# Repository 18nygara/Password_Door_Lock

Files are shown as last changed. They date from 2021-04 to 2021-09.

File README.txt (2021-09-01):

Password based door locking mechanism - 12 key allows user to input a password which will be reflected on the screen provided on the unit. USB interface allows 
one to set a password and change settings in the device, software is not included in the repo.

WARNING! ~~~ IF TRYING TO COPY THIS REPO, IT WILL NOT WORK ON YOUR LOCAL MACHINE ~~~

Because of the absolute pathing on KiCAD file libraries, downloading this project will NOT allow one to modify the design.
All footprint, 3D, and library modules were provided via UltraLibrarian, SnapEDA, DigiKey, or were custom designed - they can be resourced but not copied directly from here.

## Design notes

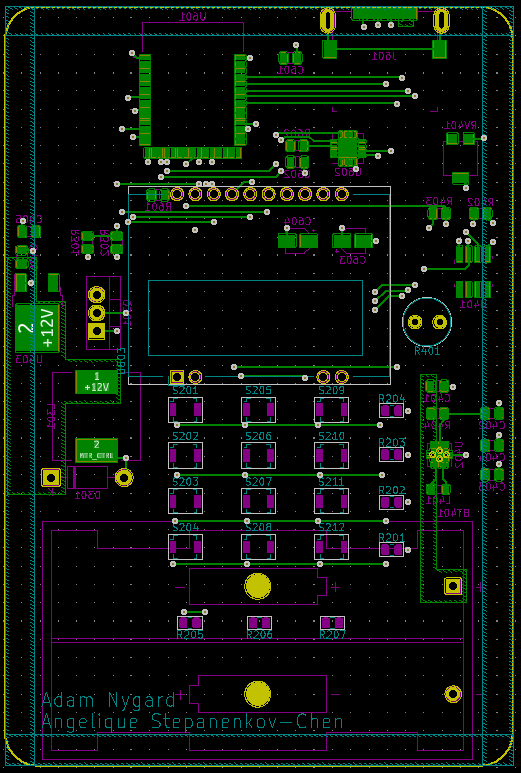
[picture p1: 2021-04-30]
PCB_3D_img/Final_Project_Bottom.PNG

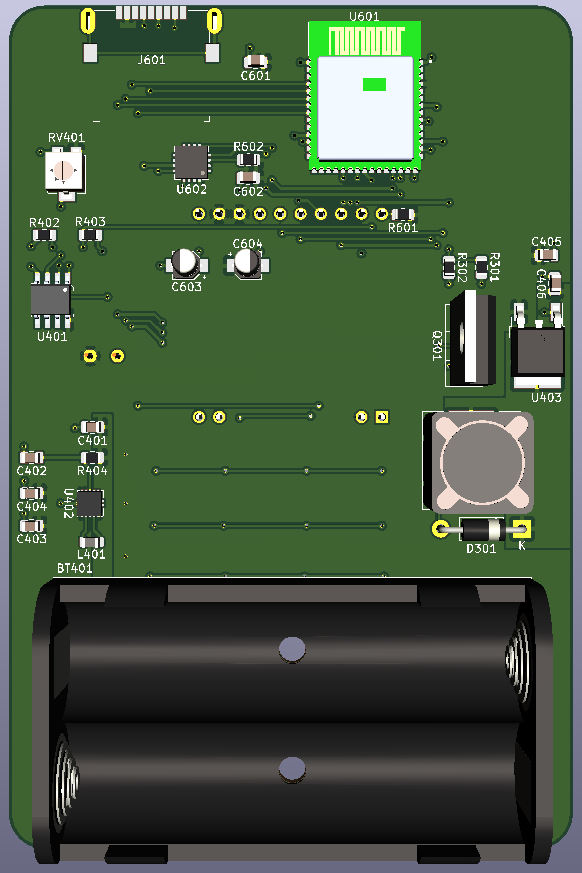
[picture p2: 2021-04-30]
PCB_3D_img/FinalProject_Bottom_3D.PNG

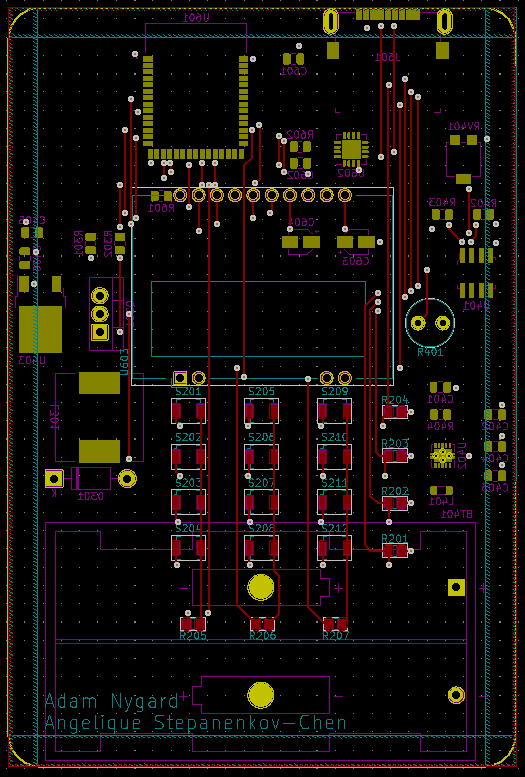
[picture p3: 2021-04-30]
PCB_3D_img/FinalProject_Top.PNG

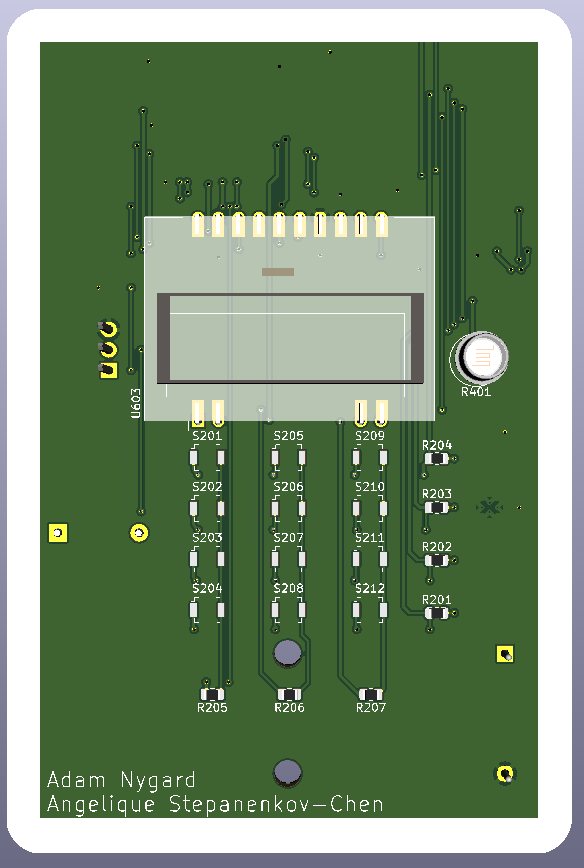
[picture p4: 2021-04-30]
PCB_3D_img/FinalProject_Top_3D.PNG

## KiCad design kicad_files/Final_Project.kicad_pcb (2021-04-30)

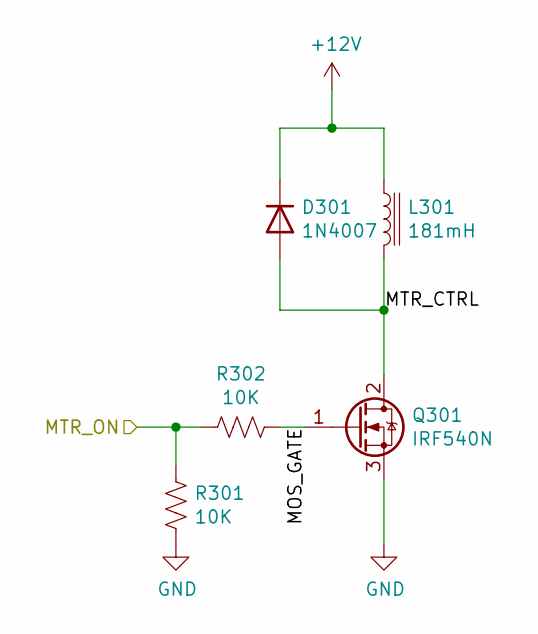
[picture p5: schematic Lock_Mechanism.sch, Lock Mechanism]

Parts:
D301: 1N4007; D_DO-41_SOD81_P10.16mm_Horizontal
L301: 181mH; L_Taiyo-Yuden_NR-10050_9.8x10.0mm
Q301: IRF540N; TO-220-3_Vertical
R301, R302: 10K; R_0805_2012Metric

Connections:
+12V: D301.1 (K), L301.1; also elsewhere on the board
/Lock_Mechanism/MOS_GATE: Q301.1 (G), R302.2
/Lock_Mechanism/MTR_CTRL: D301.2 (A), L301.2, Q301.2 (D)
/Lock_Mechanism/MTR_ON: R301.1, R302.1; also elsewhere on the board
GND: Q301.3 (S), R301.2; also elsewhere on the board

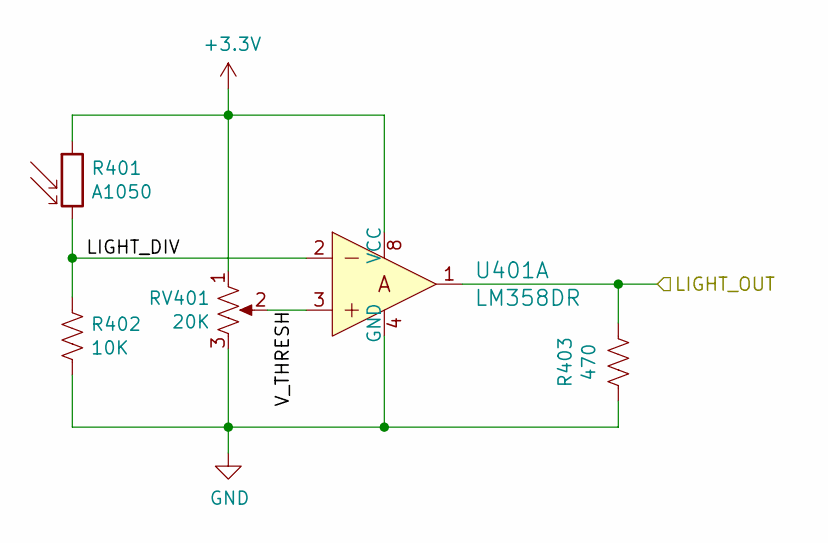
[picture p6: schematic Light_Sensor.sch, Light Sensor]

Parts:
R401: A1050; R_LDR_D6.4mm_P3.4mm_Vertical
R402: 10K; R_0805_2012Metric
R403: 470; R_0805_2012Metric
RV401: 20K; Potentiometer_Bourns_3214W_Vertical
U401: LM358DR; SOIC-8_W3.9mm; MPN LM358DR; Digi-Key_PN 296-1014-1-ND

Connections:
+3V3: R401.1, RV401.1, U401.8 (VCC); also elsewhere on the board
/Light_Sensor/LIGHT_DIV: R401.2, R402.1, U401.2
/Light_Sensor/LIGHT_OUT: R403.1, U401.1; also elsewhere on the board
/Light_Sensor/V_THRESH: RV401.2, U401.3
GND: R402.2, R403.2, RV401.3, U401.4 (GND); also elsewhere on the board

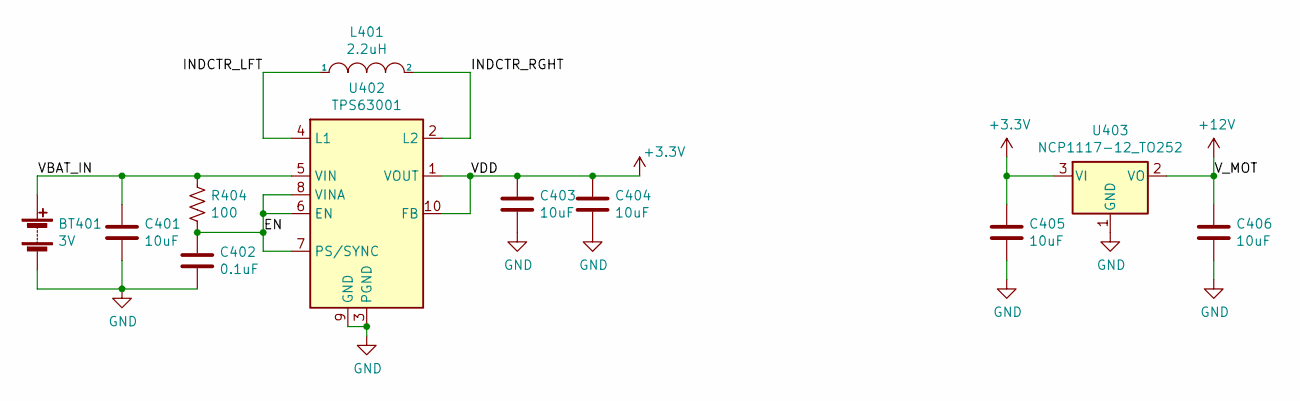
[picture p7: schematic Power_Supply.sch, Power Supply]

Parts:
BT401: 3V; BatteryHolder_Keystone_2462_2xAA
C401, C403, C404, C405, C406: 10uF; C_0805_2012Metric
C402: 0.1uF; C_0805_2012Metric
L401: 2.2uH; L_0805_2012Metric
R404: 100; R_0805_2012Metric
U402: TPS63001; Texas_DRC0010J_ThermalVias
U403: NCP1117-12_TO252; TO-252-2

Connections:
+3V3: C403.1, C404.1, C405.1, U402.1 (VOUT), U402.10 (FB), U403.3 (VI); also elsewhere on the board
+12V: C406.1, U403.2 (VO); also elsewhere on the board
/Power_Supply/EN: C402.1, R404.2, U402.6 (EN), U402.7 (PS/SYNC), U402.8 (VINA)
/Power_Supply/INDCTR_LFT: L401.1, U402.4 (L1)
/Power_Supply/INDCTR_RGHT: L401.2, U402.2 (L2)
/Power_Supply/VBAT_IN: BT401.1 (+), C401.1, R404.1, U402.5 (VIN)
GND: BT401.2 (-), C401.2, C402.2, C403.2, C404.2, C405.2, C406.2, U402.3 (PGND), U402.9 (GND), U402.11 (PGND), U403.1 (GND); also elsewhere on the board

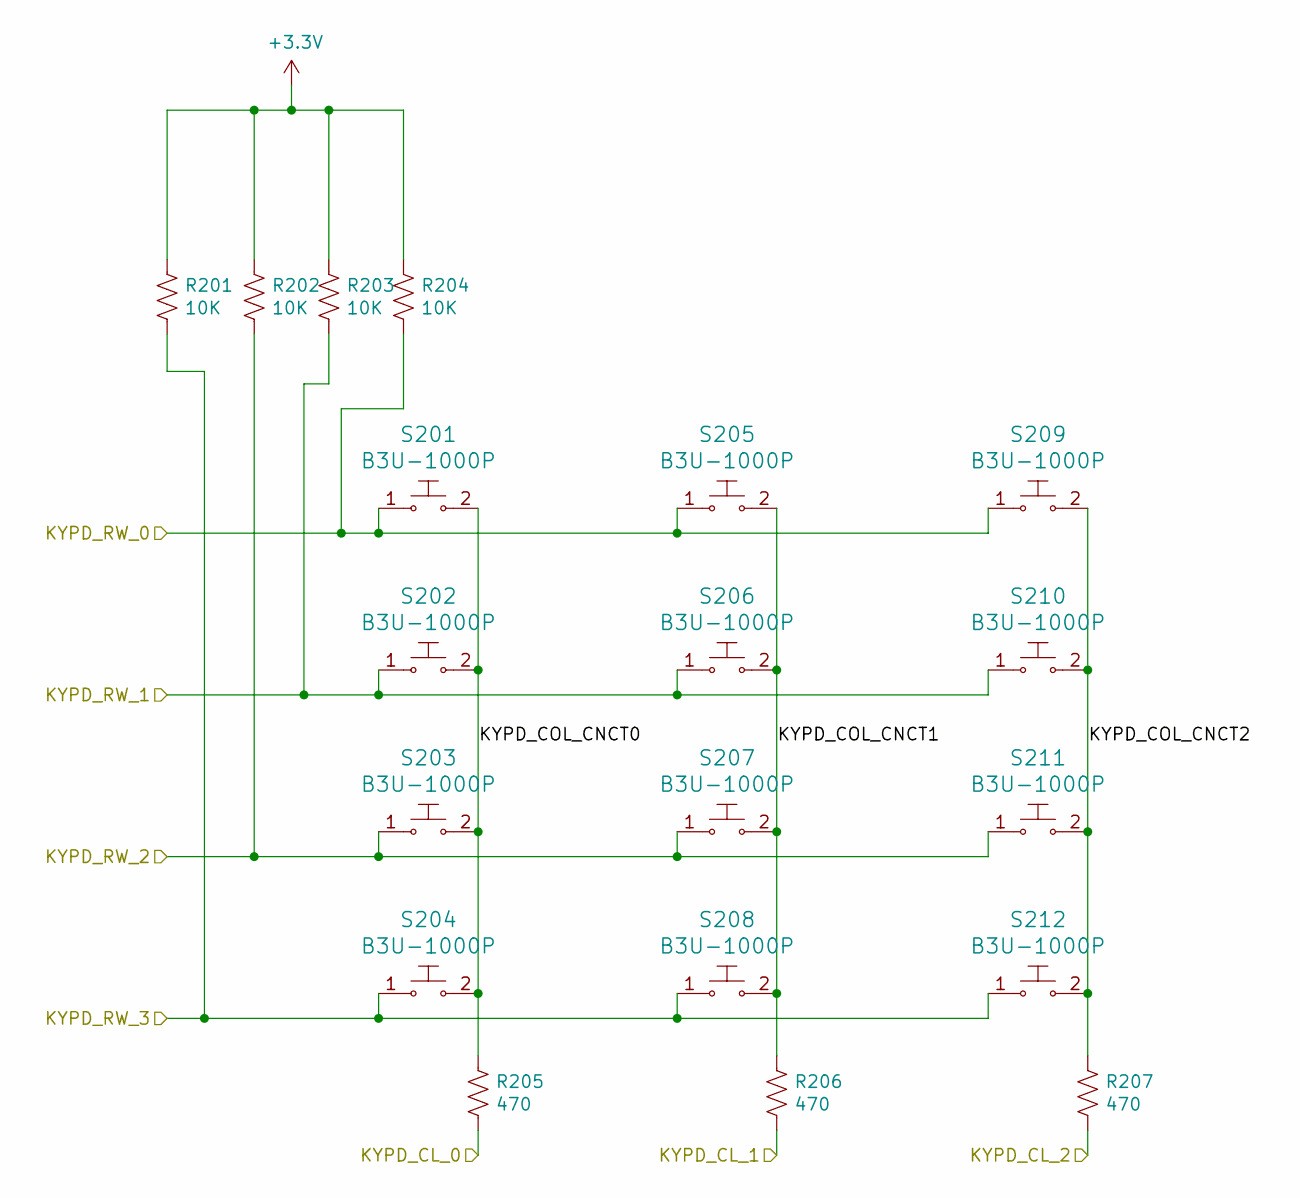
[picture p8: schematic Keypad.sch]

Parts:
R201, R202, R203, R204: 10K; R_0805_2012Metric
R205, R206, R207: 470; R_0805_2012Metric
S201, S202, S203, S204, S205, S206, S207, S208, S209, S210, S211, S212: B3U-1000P; Switch_Tactile_SMD_B3U-1000P; MPN B3U-1000P; Digi-Key_PN SW1020CT-ND

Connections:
+3V3: R201.2, R202.2, R203.2, R204.2; also elsewhere on the board
/Keypad/KYPD_CL_0: R205.2; also elsewhere on the board
/Keypad/KYPD_CL_1: R206.2; also elsewhere on the board
/Keypad/KYPD_CL_2: R207.2; also elsewhere on the board
/Keypad/KYPD_COL_CNCT0: R205.1, S201.2, S202.2, S203.2, S204.2
/Keypad/KYPD_COL_CNCT1: R206.1, S205.2, S206.2, S207.2, S208.2
/Keypad/KYPD_COL_CNCT2: R207.1, S209.2, S210.2, S211.2, S212.2
/Keypad/KYPD_RW_0: R204.1, S201.1, S205.1, S209.1; also elsewhere on the board
/Keypad/KYPD_RW_1: R203.1, S202.1, S206.1, S210.1; also elsewhere on the board
/Keypad/KYPD_RW_2: R202.1, S203.1, S207.1, S211.1; also elsewhere on the board
/Keypad/KYPD_RW_3: R201.1, S204.1, S208.1, S212.1; also elsewhere on the board

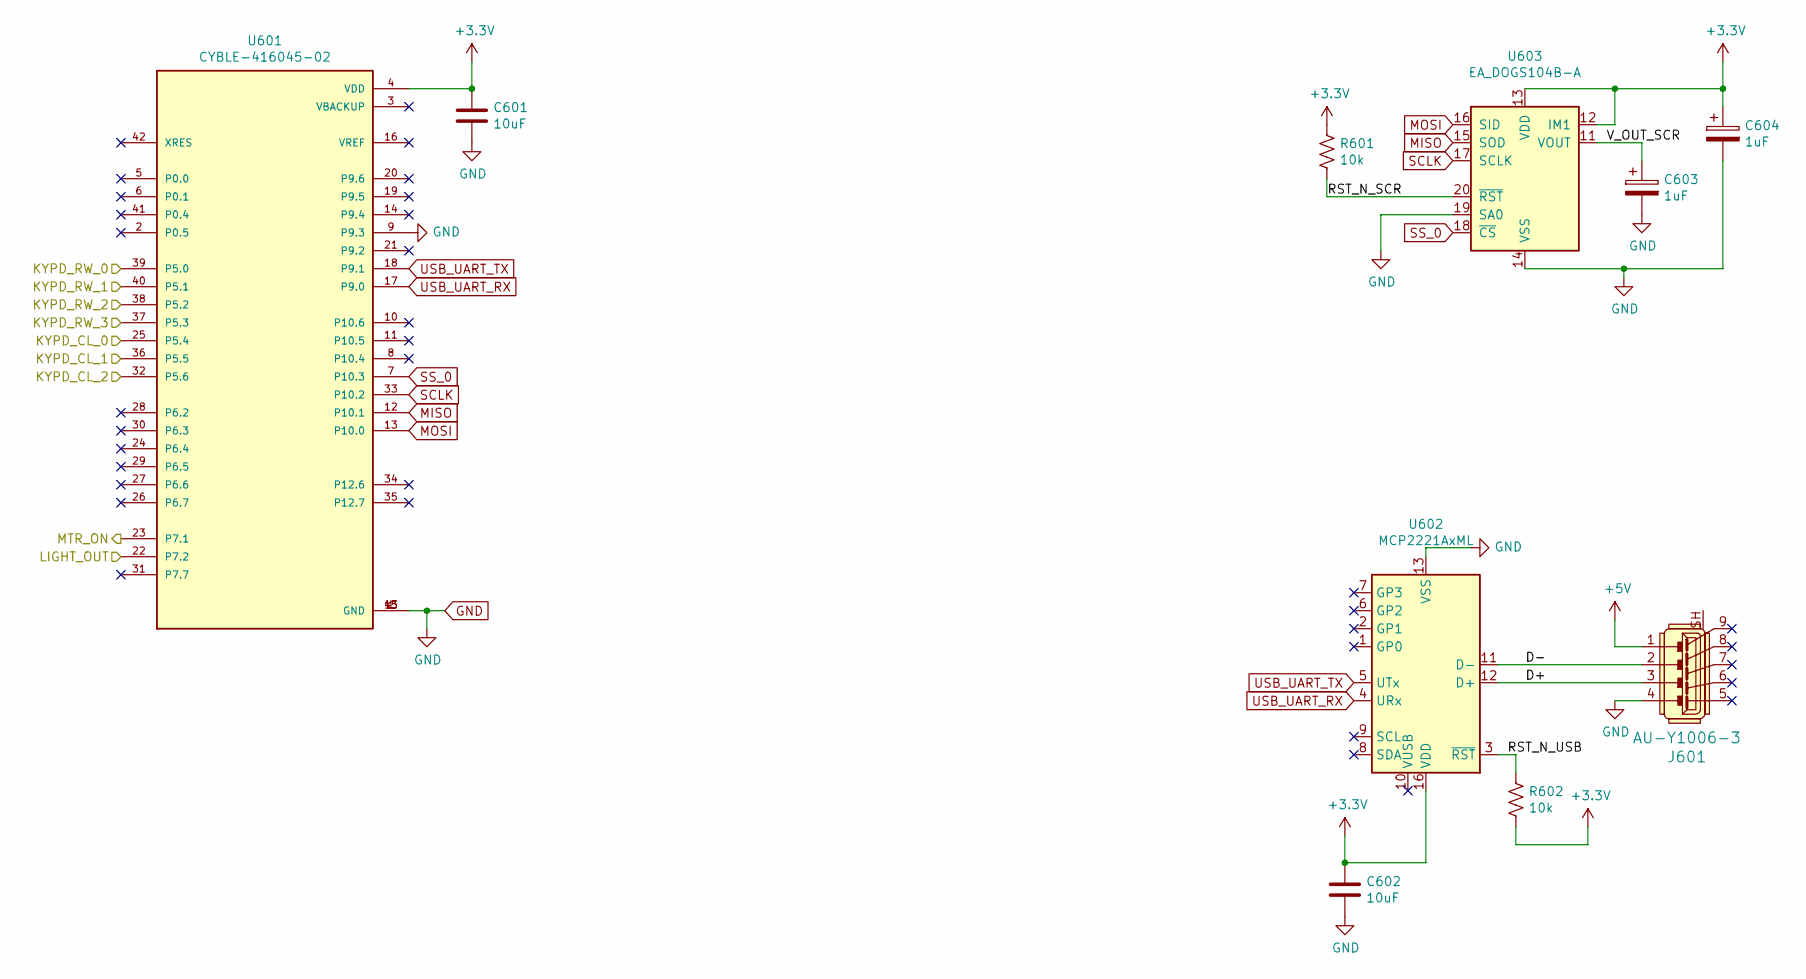
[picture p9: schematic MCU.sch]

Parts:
C601, C602: 10uF; C_0805_2012Metric
C603, C604: 1uF; CP_Elec_3x5.3
J601: AU-Y1006-3; USB_A_Female_AU-Y1006-3; MPN AU-Y1006-3; Digi-Key_PN AE10704-ND
R601, R602: 10k; R_0805_2012Metric
U601: CYBLE-416045-02; XCVR_CYBLE-416045-02; PARTREV A
U602: MCP2221AxML; QFN-16-1EP_4x4mm_P0.65mm_EP2.5x2.5mm
U603: EA_DOGS104B-A; EA_DOGS104X-A

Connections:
+3V3: C601.1, C602.1, C604.1, R601.1, R602.2, U601.4 (VDD), U602.16 (VDD), U603.12 (IM1), U603.13 (VDD); also elsewhere on the board
+5V: J601.1
/Keypad/KYPD_CL_0: U601.25 (P5.4); also elsewhere on the board
/Keypad/KYPD_CL_1: U601.36 (P5.5); also elsewhere on the board
/Keypad/KYPD_CL_2: U601.32 (P5.6); also elsewhere on the board
/Keypad/KYPD_RW_0: U601.39 (P5.0); also elsewhere on the board
/Keypad/KYPD_RW_1: U601.40 (P5.1); also elsewhere on the board
/Keypad/KYPD_RW_2: U601.38 (P5.2); also elsewhere on the board
/Keypad/KYPD_RW_3: U601.37 (P5.3); also elsewhere on the board
/Light_Sensor/LIGHT_OUT: U601.22 (P7.2); also elsewhere on the board
/Lock_Mechanism/MTR_ON: U601.23 (P7.1); also elsewhere on the board
/MCU/D+: J601.3, U602.12 (D+)
/MCU/D-: J601.2, U602.11 (D-)
/MCU/RST_N_SCR: R601.2, U603.20 (~RST)
/MCU/RST_N_USB: R602.1, U602.3 (~RST)
/MCU/V_OUT_SCR: C603.1, U603.11 (VOUT)
GND: C601.2, C602.2, C603.2, C604.2, J601.4, U601.1 (GND), U601.9 (P9.3), U601.15 (GND), U601.43 (GND), U602.13 (VSS), U603.14 (VSS), U603.19 (SA0); also elsewhere on the board
MISO: U601.12 (P10.1), U603.15 (SOD)
MOSI: U601.13 (P10.0), U603.16 (SID)
SCLK: U601.33 (P10.2), U603.17 (SCLK)
SS_0: U601.7 (P10.3), U603.18 (~CS)
USB_UART_RX: U601.17 (P9.0), U602.4 (URx)
USB_UART_TX: U601.18 (P9.1), U602.5 (UTx)

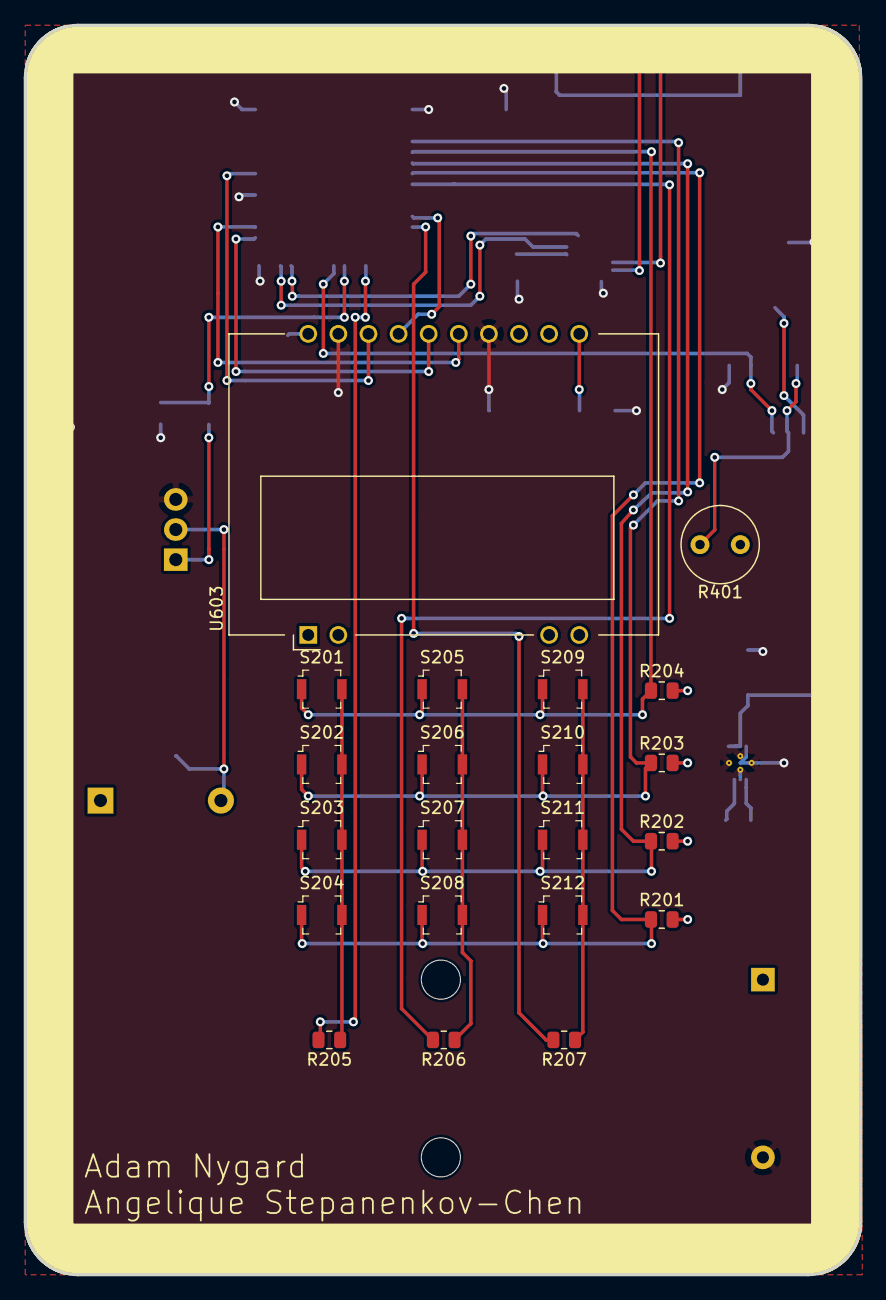
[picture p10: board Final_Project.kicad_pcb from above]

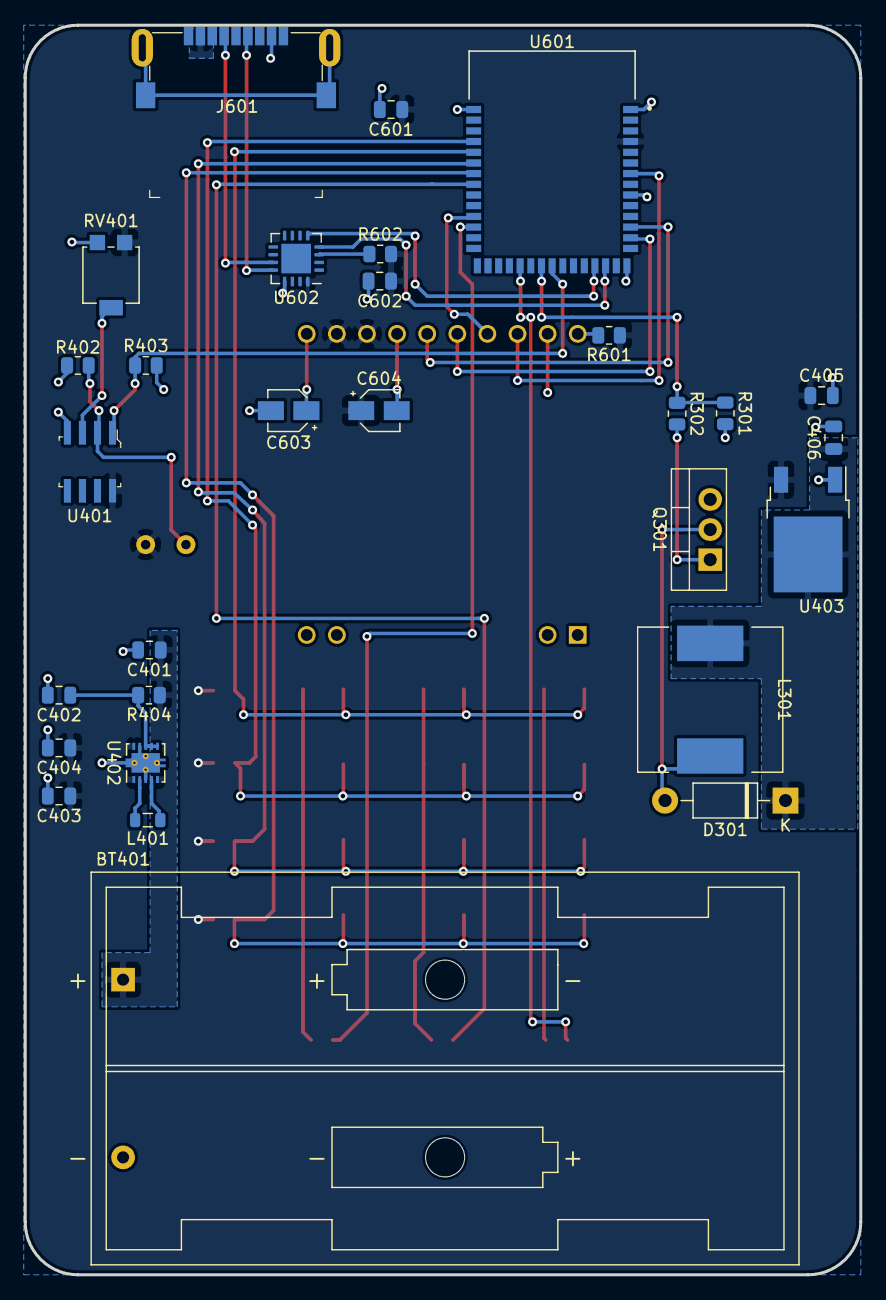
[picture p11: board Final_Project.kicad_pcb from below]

Board: 2 copper layers, 70.5 x 105.4 mm, 50 parts (29 on the bottom side), 34 nets.

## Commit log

2021-04-30 Add initial KiCAD files
    [Final_Project.kicad_pcb, Final_Project.sch, Keypad.sch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]
2021-04-30 Add PCB and 3D rendering images of the final product
